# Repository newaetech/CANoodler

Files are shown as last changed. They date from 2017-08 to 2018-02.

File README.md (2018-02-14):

# CANoodler #
CAN to 3.3V logic level interface. Dumb. Cheap. Simple. Pick 3.

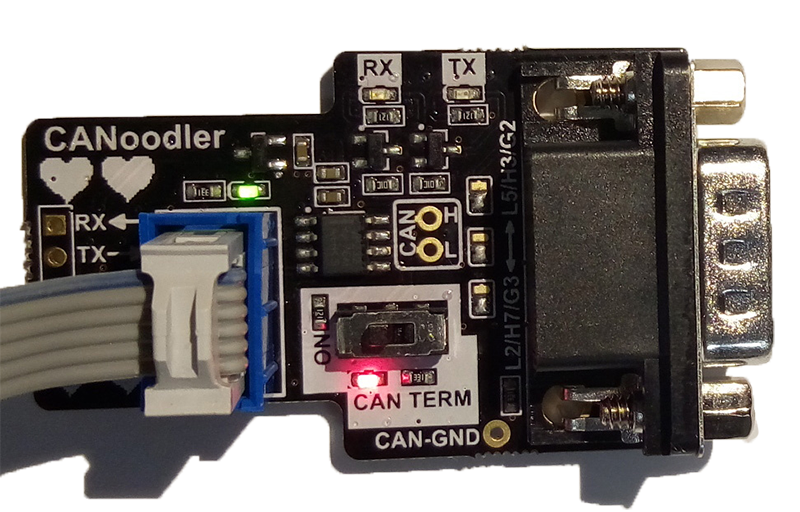
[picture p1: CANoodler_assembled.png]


## About CANoodler ##

CANoodler is a simple CAN (not CAN-FD) interface, which provides logic-level 3.3V output. It's designed to be used with microcontrollers that have CAN blocks inside them, and in particular uses a pinout on some ChipWhisperer CW308 (UFO) Target boards.

It's kinda nice (I think anyway) since it has these features:

* LEDs for TX/RX (uses MOSFET to drive LEDs so doesn't slow your I/O pins down).
* Reverse-polarity protection on 3.3V input.
* Switch for CAN termination on/off with LED feedback.

As CANoodler is not isolated, be aware you should be careful using this in a high-noise environment. The CAN-GND and I/O GND are connected directly together on this board.

## Getting CANoodler ##

CANoodler is sold by NewAE Technology Inc., but it's open-source hardware so you can just build one. See below for build instructions if you don't want to give us money.

## Using CANoodler ##

CANoodler is simple to use. Simply:

* Connect the RX pin to your microcontroller CAN-RX pin (this is an OUTPUT from the CANoodler).
* Connect the TX pin to your microcontroller CAN-TX pin (this is an INPUT to the CANoodler).
* Provide 3.3V power to the board.
* Select if you'd like the termination resistor ON or OFF with the switch.
* Write an entire CAN stack for your microcontroller from scratch, along with a test framework to ensure you meet applicable relevant standards.

The solder jumpers specify which pinout you'd like on the male DB9 connector.

The default pinout is selected by shorting the LOWER and MIDDLE solder jumpers. It is used by many boards and the Peak CAN USB interface:

* CAN-Low = Pin 2
* CAN-High = Pin 7
* CAN-GND = Pin 3

The "option" pinout is set by moving each of the three solder jumpers to short the UPPER and MIDDLE pads. This pinout is used by cheap ODB-II to DB9 connectors:

* CAN-Low = Pin 5
* CAN-High = Pin 3
* CAN-GND = Pin 2

## Building CANoodler ##

To build CANoodler, you'll need the following:

* CANoodler PCB.
* Parts for CANoodler.
* Ability to solder and/or coerce someone who can solder into doing your work

### CANoodler PCB ###

You can order the PCB from [OSH Park](https://oshpark.com/projects/aEDxzHX4) or upload the gerber zip-file somewhere you like.

The CANoodler PCB doesn't have part designators on the PCB. Not because I have you and want to make it hard-mode to build your own, but because I prefer having a cleaner final PCB and planned on mostly assembling these with a pick-n-place machine.

There is an assembly drawing you will need to refer to when building the unit.

### CANoodler Parts ###

There is a BOM in a .XLS file, and you can get a [Digi-Key (US) Shared Cart](http://www.digikey.com/short/310jp5) or [Digi-Key (Canada) Shared Cart](http://www.digikey.ca/short/310jp5). Those links should easily translate to other countries too.

The parts list is pretty standard. The only gotcha is the 0603 size resistor for the 120-ohm CAN termination should be a 1/4W device. I recommend using P/N ERJ-PA3F1200V (this is what is used in the production built units), since it is "pulse rated" so should deal with overload a little better. 

If you use a 1/10W (standard 0603) it will be mostly fine, as the CAN bus will idle around 2.5V, which means a constant 1/20W dissipation in your resistor. But if anything goes wrong (short to +5V even) you might burn up the resistor.

## License ##

The schematic lists the license as LGPL, which is good enough I hope. 

## CANoodler Name ##

If you've gotten this far and didn't figure it out, the name is a joke on the word "[canoodle](https://www.merriam-webster.com/dictionary/canoodle)". Hence all the hearts on the PCB. I tried anyway.

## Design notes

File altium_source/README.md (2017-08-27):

The PCB source files will go here - the design uses my own libraries with a bunch of crap in them, so I need to still make a project library instead. I haven't cleaned it up to do that but will upload the source shortly (there is an open issue for this).

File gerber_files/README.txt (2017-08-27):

2-Layer PCB

Soldermask: Black
Silkscreen: White

Finish: Immersion Gold

Board Files:

 .GM1 - PCB Panel
 .GTO - Top Silkscreen
 .GTS - Top Soldermask
 .GTL - Top Copper
 .GBL - Bottom Copper
 .GBS - Bottom Soldermask
 .GBO - Bottom Silkscreen
 .XLN - Drill File

Other Files:

 .GTP - Top Paste (used for stencil)
 .GBP - Bottom Paste (NOT USED)

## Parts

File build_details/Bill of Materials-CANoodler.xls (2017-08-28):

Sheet: BOM Report
Bill of Materials
Source Data From: |  | CANoodler.SchDoc
Project: |  | CANoodler REV 01
Variant: |  | None
Creation Date: | 26/08/2017 | 9:46:04 PM
Print Date: | 2017-08-28 | 8:55:45
Production Quantity: | 1
 | Designator | Quantity | Description | Comment | Footprint | Supplier 1 | Supplier Part Number 1
 | C1, C2 | 2 | 2u2, 0603 | 2u2 | CAPC0603_M | Digi-Key | 1276-1134-1-ND
 | C3 | 1 | 100n, 0603 | 100n | CAPC0603_M | Digi-Key | 399-5089-1-ND
 | D1, D4 | 2 | Chip LED, Red | LED, 0603, Red | LED-0603-RED | Digi-Key | 754-1122-1-ND
 | D2, D3 | 2 | Chip LED, Green | LED, 0603, Green | LED-0603-GREEN | Digi-Key | 754-1116-1-ND
 | J1 | 1 | HDR, Male, 6-Pin, 2 Row, Shrouded | HDR | HDR_6PIN_2ROW_SHROUD | Digi-Key | 609-2845-ND (https://octopart-clicks.com/click/altium?sku=609-2845-ND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)
 | J2 | 1 | DB9 R/A Connector, Through-hole, Male | A-DS 09 A/KG-T2S | TAIT-DRB-09P11G1R_V | Digi-Key | AE10968-ND
 | J3 | 1 | 4-Pin Header
 | Q1, Q2, Q3 | 3 | P-Channel, 3A, Logic Level | DMP2123LQ-7 | SOT95P245X110-3M | Digi-Key | DMP2123LQ-7DICT-ND (https://octopart-clicks.com/click/altium?manufacturer=Diodes%20Incorporated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)
 | R1, R5, R6 | 3 | 330R res, 0603, 1%, 1/10W | 330R | RESC1608X55N | Digi-Key | 311-330HRCT-ND (https://octopart-clicks.com/click/altium?sku=311-330HRCT-ND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)
 | R2 | 1 | 120R res, 0603, 1%, 1/4W, PULSE | 120R, 1%, 1/4W | RESC1608X55N | Digi-Key | P120BYCT-ND
 | R3, R4 | 2 | 10k res, 0603, 1%, 1/10W | 10k | RESC1608X55N | Digi-Key | 311-10.0KHRCT-ND (https://octopart-clicks.com/click/altium?sku=311-10.0KHRCT-ND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)
 | R7, R8 | 2 | 120R res, 0603, 1%, 1/10W | 120R | RESC1608X55N | Digi-Key | 311-120HRCT-ND (https://octopart-clicks.com/click/altium?sku=311-120HRCT-ND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)
 | S1 | 1 | Switch, Slide SMD, Gull, DPDT | JS202011JCQN | JS202011JCQN | Digi-Key | CKN10723CT-ND (https://octopart-clicks.com/click/altium?sku=CKN10723CT-ND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)
 | U1 | 1 | CAN Transceiver, 3.3V | SN65HVD232DR | SOIC8_NARROW | Digi-Key | 296-26344-1-ND (https://octopart-clicks.com/click/altium?sku=296-26344-1-ND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)
 |  | 23
Approved |  | Notes

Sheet: Project Information
Project Full Path | C:\Users\colin\Dropbox (NewAE Technology Inc)\engineering\git_repos\CANoodler\CANoodler_pcb\CANoodler_pcb.PrjPcb
Project Filename | CANoodler_pcb.PrjPcb
Variant Name | None
Data-Source Filename | CANoodler.SchDoc
Data-Source Full Path | C:\Users\colin\Dropbox (NewAE Technology Inc)\engineering\git_repos\CANoodler\CANoodler_pcb\CANoodler.SchDoc
Title | Bill of Materials For Schematic Document [CANoodler.SchDoc]
Total Quantity | 23
Report Time | 9:46:04 PM
Report Date | 26/08/2017
Report Date & Tine | 26/08/2017 9:46:04 PM
Output Name | Bill of Materials
Output Type | BOM_PartType
Output Generator Name | BOM
Output Generator Description | Bill of Materials

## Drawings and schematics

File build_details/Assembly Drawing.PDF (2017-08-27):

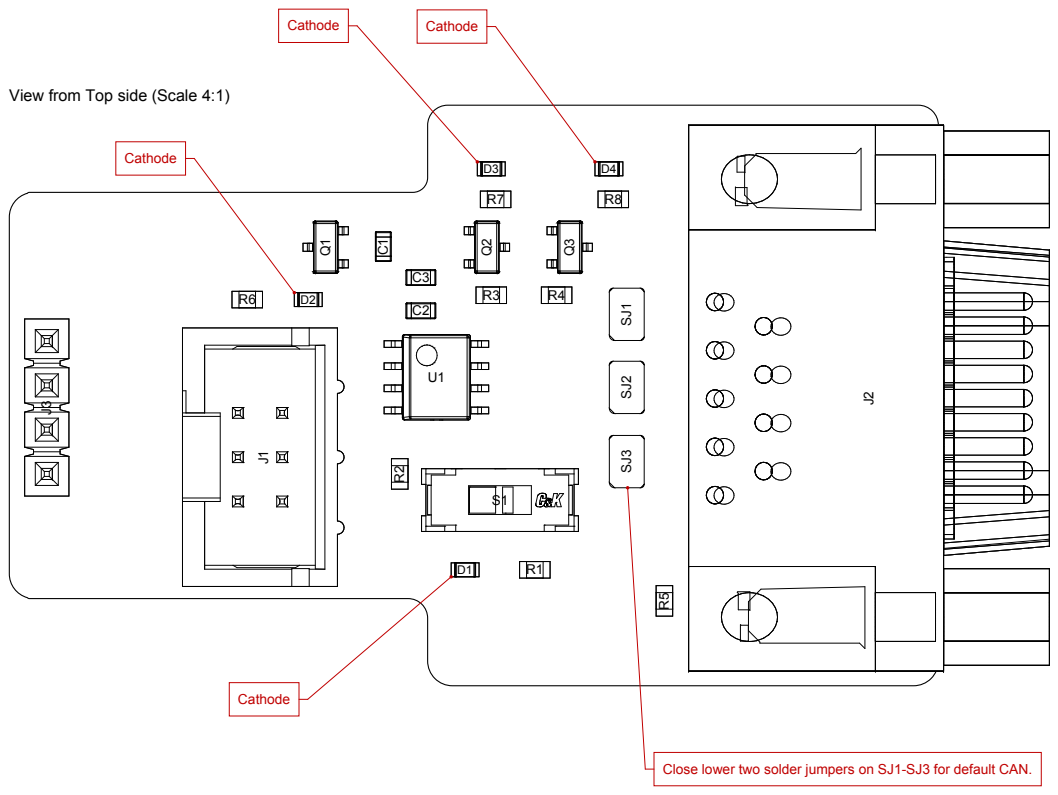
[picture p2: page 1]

View from Top side (Scale 4:1)

Close lower two solder jumpers on SJ1-SJ3 for default CAN.

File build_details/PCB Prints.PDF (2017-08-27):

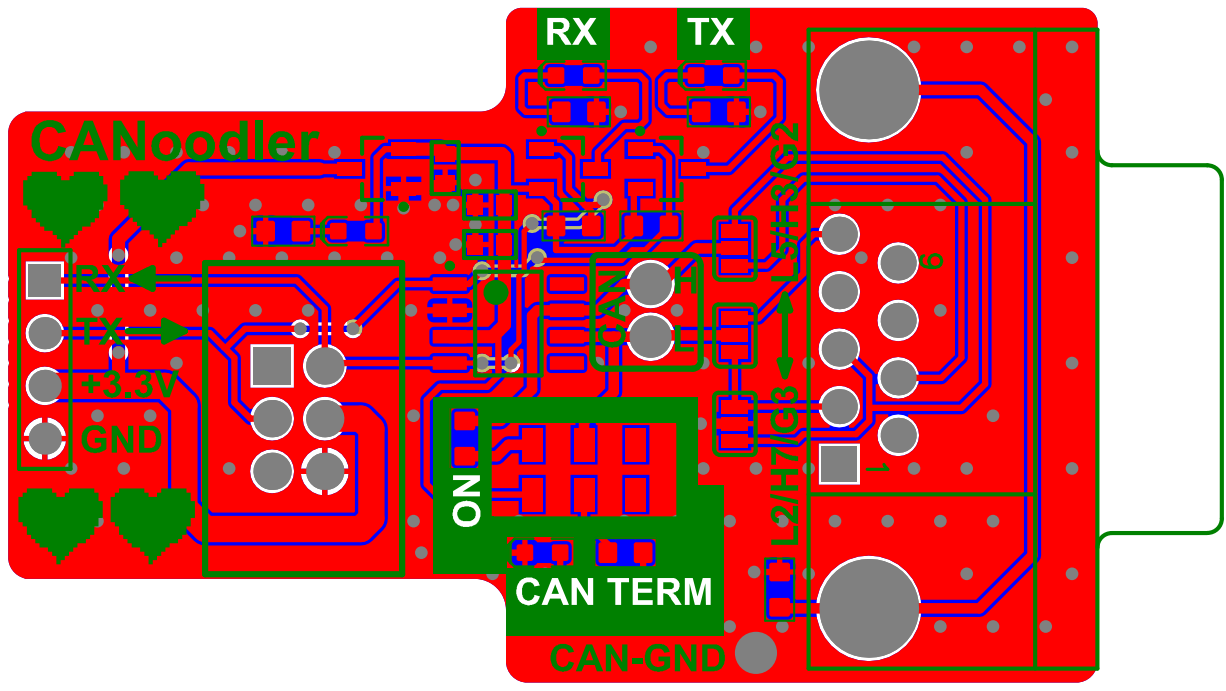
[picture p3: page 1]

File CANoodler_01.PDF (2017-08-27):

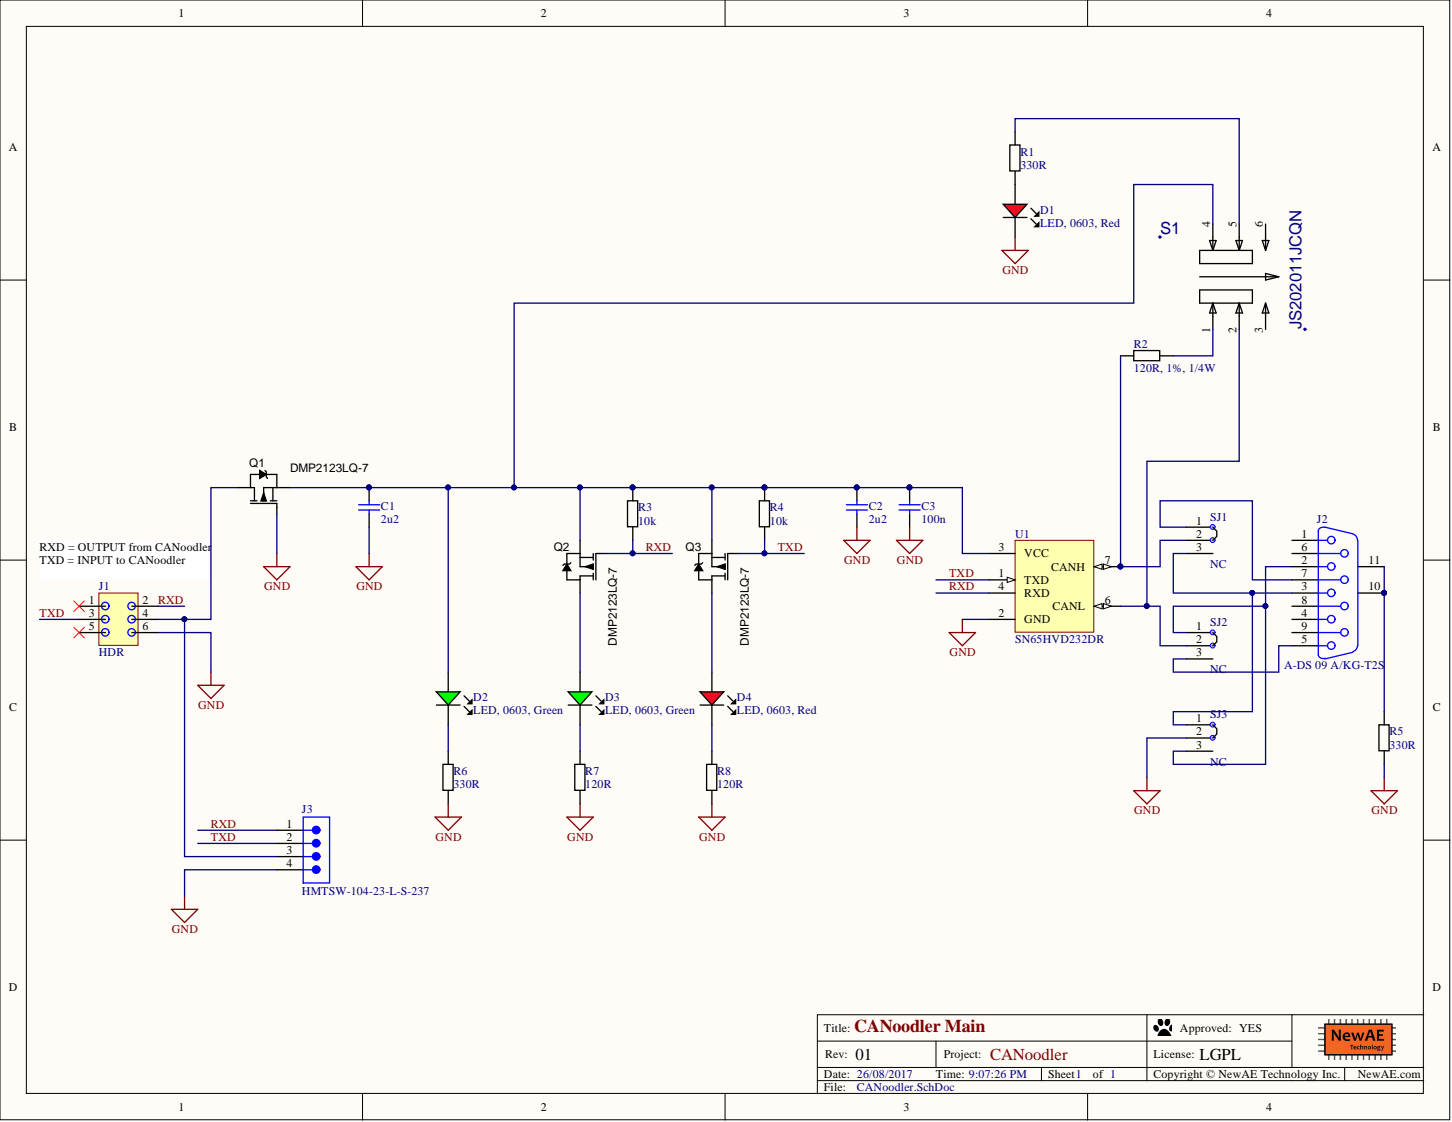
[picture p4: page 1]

RXD = OUTPUT from CANoodler
TXD = INPUT to CANoodler

CANoodler Main Title: | Approved: YES

Rev: 01 | Project: CANoodler | License: LGPL

Date: 26/08/2017 Time: 9:07:26 PM | Sheet 1 of 1

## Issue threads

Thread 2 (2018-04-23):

Used for writing?

keesj, 2018-04-23:
Hello

I would like to use the Canoodler to write to the can bus.

From reading the data sheet of the sn65hvd252 I would need to set pin 8 (S)
to high to enable the TX out but I do not see this pin exposed anywhere on the bus.

am I missing something?
http://www.ti.com/lit/ds/symlink/sn65hvd252.pdf

colinoflynn, 2018-04-23:
The P/N is SN65HVD232D - that has pin 8 as a N/C.

keesj, 2018-04-23:
I see thank you!
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

Closed 2018-04-23.

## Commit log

2017-08-27 Initial Import - Schematic + PCB files. Need to export altium libraries etc into source.
    [CANoodler.GBL, CANoodler.GBO, CANoodler.GBP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]
2017-08-27 Update readme, add BOM
    [Bill of Materials-CANoodler.xls]
2017-08-28 Fix BOM, add link to digikey shared cart
    [Bill of Materials-CANoodler.xls]
